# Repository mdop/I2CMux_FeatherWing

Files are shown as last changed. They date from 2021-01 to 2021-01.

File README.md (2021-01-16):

# I2CMux FeatherWing

This project is a shield for Adafruits 'Feather' delelopment board series. It is designed to provide 6 STEMMA Qt and 2 STEMMA/STEMMA Qt (or equivalent) I2C outputs which can be set to 2 different voltage levels.

**Suggested Applications**
* Use 5V only sensors with Feather-boards
* Utilize multiple I2C gadgets with same address

**Features**
* Can connect up to 8 I2C gadgets with identical address.
* I2C Channels 0-3 and 4-7 and their respective power can be independently set to voltage levels 3.3V/V_USB/V_BAT
* Channel 1-3 and 5-7 have JST-SH headers compatible with STEMMA Qt and compatible devices without adapter. Channel 0 and 4 can be connected to a JST-PH (STEMMA format) or SH header, both footprints are available.

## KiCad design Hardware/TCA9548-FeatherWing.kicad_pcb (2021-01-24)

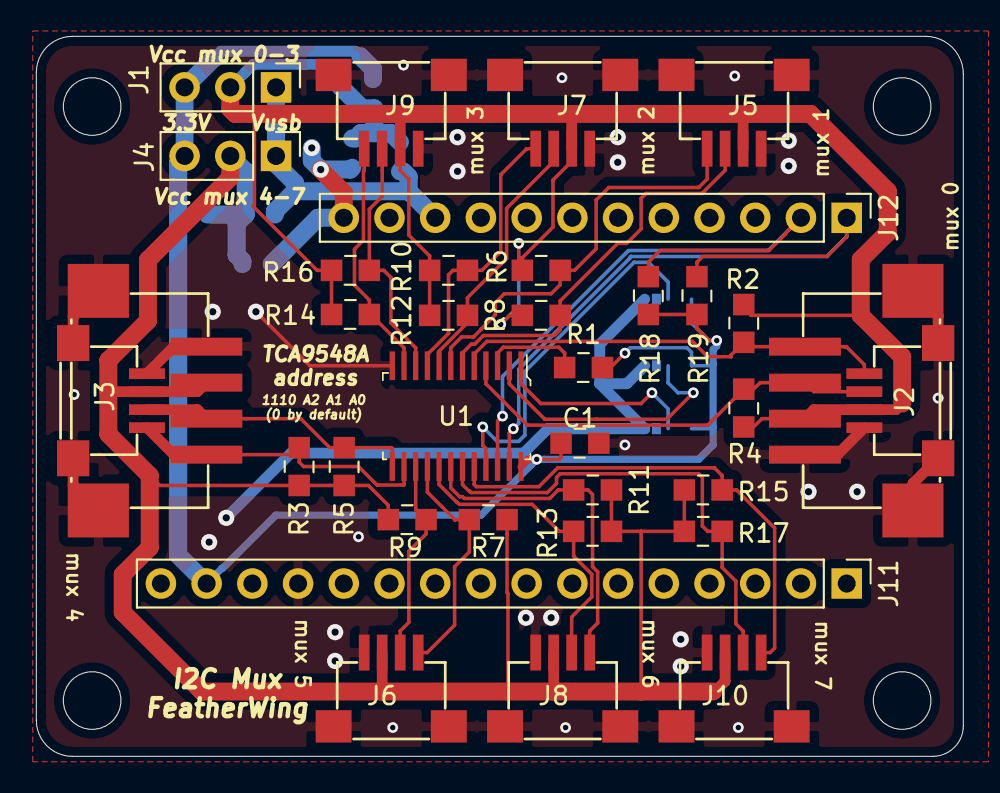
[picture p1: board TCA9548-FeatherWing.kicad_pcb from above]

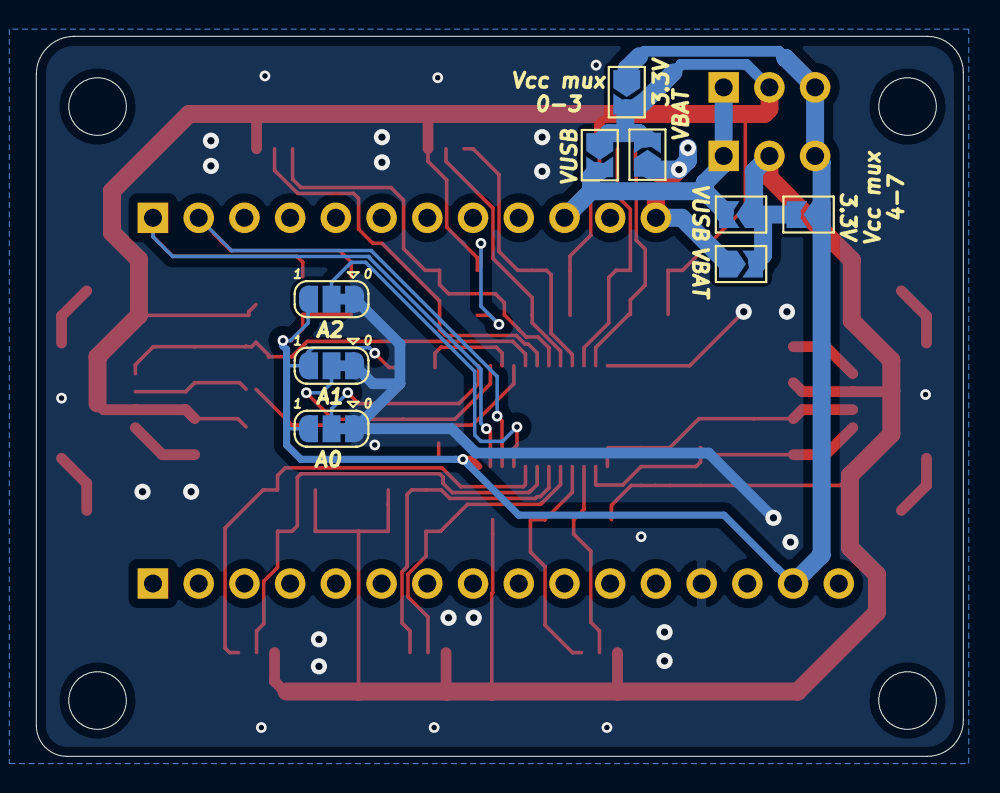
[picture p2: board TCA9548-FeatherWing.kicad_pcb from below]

Board: 2 copper layers, 51.5 x 40.0 mm, 46 parts (9 on the bottom side), 28 nets.

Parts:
C1: 1u; 0805
H1, H2, H3, H4: MountingHole; MountingHole_3.2mm_M3_DIN965
J1, J4: Conn_01x03; PinHeader_1x03_P2.54mm_Vertical
J2, J3: JST_PH-SH; JST_PH-SH_4x1
J5, J6, J7, J8, J9, J10: JST_SH; JST_SH_4x1
J11: Conn_01x16; PinHeader_1x16_P2.54mm_Vertical
J12: Conn_01x12; PinHeader_1x12_P2.54mm_Vertical
JP1, JP2, JP3: SolderJumper_3_Bridged12; SolderJumper-3_P1.3mm_Bridged12_RoundedPad1.0x1.5mm
JP4, JP5, JP6, JP7, JP8, JP9: SolderJumper_2_Open; SolderJumper-2_P1.3mm_Open_TrianglePad1.0x1.5mm
R1, R2, R3, R4, R5, R6, R7, R8, R9, R10, R11, R12, R13, R14, R15, R16, R17, R18, R19: 10k; 0805
U1: TCA9548APWR; TSSOP-24_W4.40mm

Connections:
+3V3: C1.1, J1.3, J4.3, J11.15, JP1.3, JP2.3, JP3.3, JP4.1, JP7.1, R1.2, R18.1, R19.1, U1.24
BAT: J12.12, JP6.1, JP9.1
GND: C1.2, J2.0, J2.1, J3.0, J3.1, J5.0, J5.1, J6.0, J6.1, J7.0, J7.1, J8.0, J8.1, J9.0, J9.1, J10.0, J10.1, J11.13, JP1.1, JP2.1, JP3.1, U1.12
I2C_V1: J1.2, J2.2, J5.2, J7.2, J9.2, JP4.2, JP5.1, JP6.2, R2.1, R4.1, R6.1, R8.1, R10.1, R12.1, R14.1, R16.1
I2C_V2: J3.2, J4.2, J6.2, J8.2, J10.2, JP7.2, JP8.1, JP9.2, R3.1, R5.1, R7.1, R9.1, R11.1, R13.1, R15.1, R17.1
unnamed: J2.3, R4.2, U1.4
unnamed: J2.4, R2.2, U1.5
unnamed: J3.3, R5.2, U1.13
unnamed: J3.4, R3.2, U1.14
unnamed: J5.3, R8.2, U1.6
unnamed: J5.4, R6.2, U1.7
unnamed: J6.3, R9.2, U1.15
unnamed: J6.4, R7.2, U1.16
unnamed: J7.3, R12.2, U1.8
unnamed: J7.4, R10.2, U1.9
unnamed: J8.3, R13.2, U1.17
unnamed: J8.4, R11.2, U1.18
unnamed: J9.3, R16.2, U1.10
unnamed: J9.4, R14.2, U1.11
unnamed: J10.3, R17.2, U1.19
unnamed: J10.4, R15.2, U1.20
unnamed: JP1.2, U1.1
unnamed: JP2.2, U1.2
unnamed: JP3.2, U1.21
unnamed: R1.1, U1.3
SCL: J12.2, R18.2, U1.22
SDA: J12.1, R19.2, U1.23
V_USB: J1.1, J4.1, J12.10, JP5.2, JP8.2

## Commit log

2021-01-16 First version of schematic and board
    Also update readme
    [TCA9548-FeatherWing.kicad_pcb, TCA9548-FeatherWing.sch]
2021-01-24 Add pullups to source lines
    [TCA9548-FeatherWing.kicad_pcb, TCA9548-FeatherWing.sch]
